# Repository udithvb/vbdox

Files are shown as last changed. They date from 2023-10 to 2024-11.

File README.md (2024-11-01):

DIY ergonomic keyboard clone "inspired" by Ergodox.

Source code for:
  1. PCB design in Kicad
  2. Keyboard layout using KLE.
  3. 3D model using Onshape
  4. Config files for KMK for firmware.

3D model files here https://cad.onshape.com/documents/ee7b6b641733c3f6c864279a/w/8fba0d1b41314f945c99cf82/e/c87f91dc97543009856402ba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

WhatsApp Image 2024-07-17 at 08 57 51

Clipped_image_20231214_193427

wiki:
	for flasing to rom hold bootsel before plugging -> mv to rpi folder
	for src code hold reset before plugging in + reset within 500ms -> mv to circuitpy folder

Use thonny, configure interpreter to circuipy generic device, uncomment debug to read serial console.

Rename boards for split to work:
	https://learn.adafruit.com/welcome-to-circuitpython/renaming-circuitpy

links for binaries:
	https://www.raspberrypi.com/documentation/microcontrollers/pico-series.html#resetting-flash-memory
	https://circuitpython.org/board/waveshare_rp2040_zero/
	https://github.com/KMKfw/kmk_firmware/blob/master/docs/en/Getting_Started.md

Edit config:
	Hold the reset key before plugging in, keep holding for 4 seconds after (topmost key on keeb) to get into the filesystem and edit config.

# Credits

-   Keyboard parts compiled by [joe-scotto ](https://github.com/joe-scotto/scottokeebs/tree/main/Extras/ScottoKicad).
-   Reversible hotswap sockets by [LouWii ](https://github.com/LouWii/ErgoMax/tree/master/libs).

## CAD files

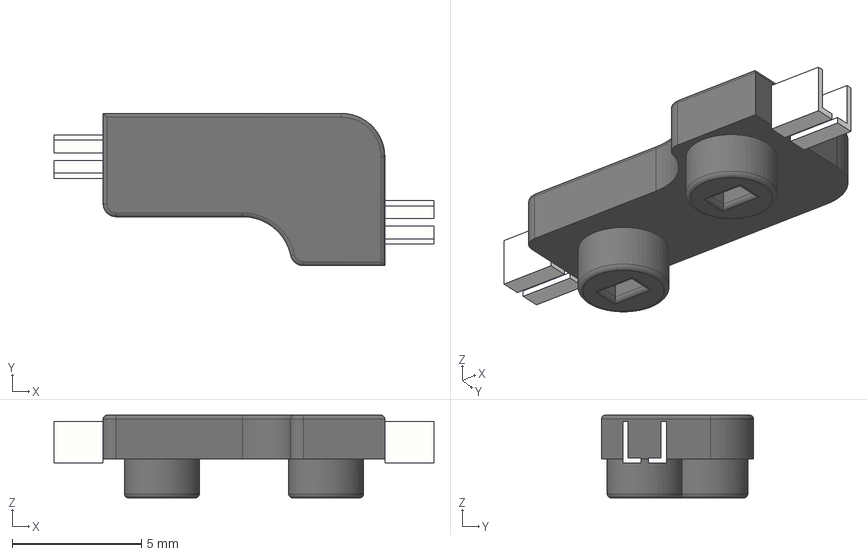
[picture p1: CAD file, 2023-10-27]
hardware/kicad_libs/3dmodels/Kailh_Socket.step
14.7 x 5.89 x 3.20 mm

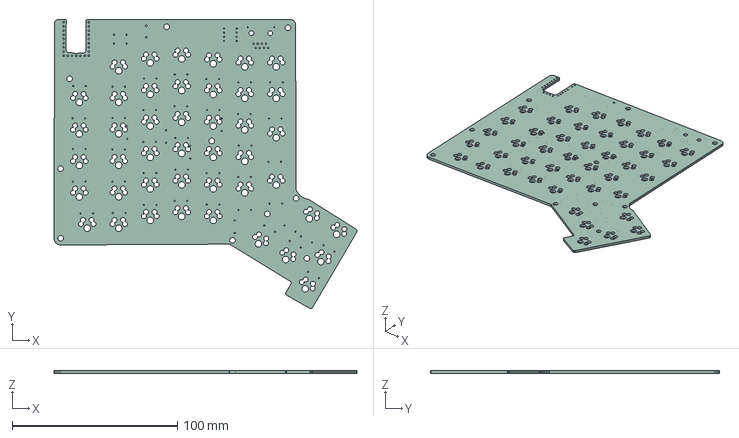
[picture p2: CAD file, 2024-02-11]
hardware/pcb/pcb.step
183.2 x 174.8 x 1.60 mm

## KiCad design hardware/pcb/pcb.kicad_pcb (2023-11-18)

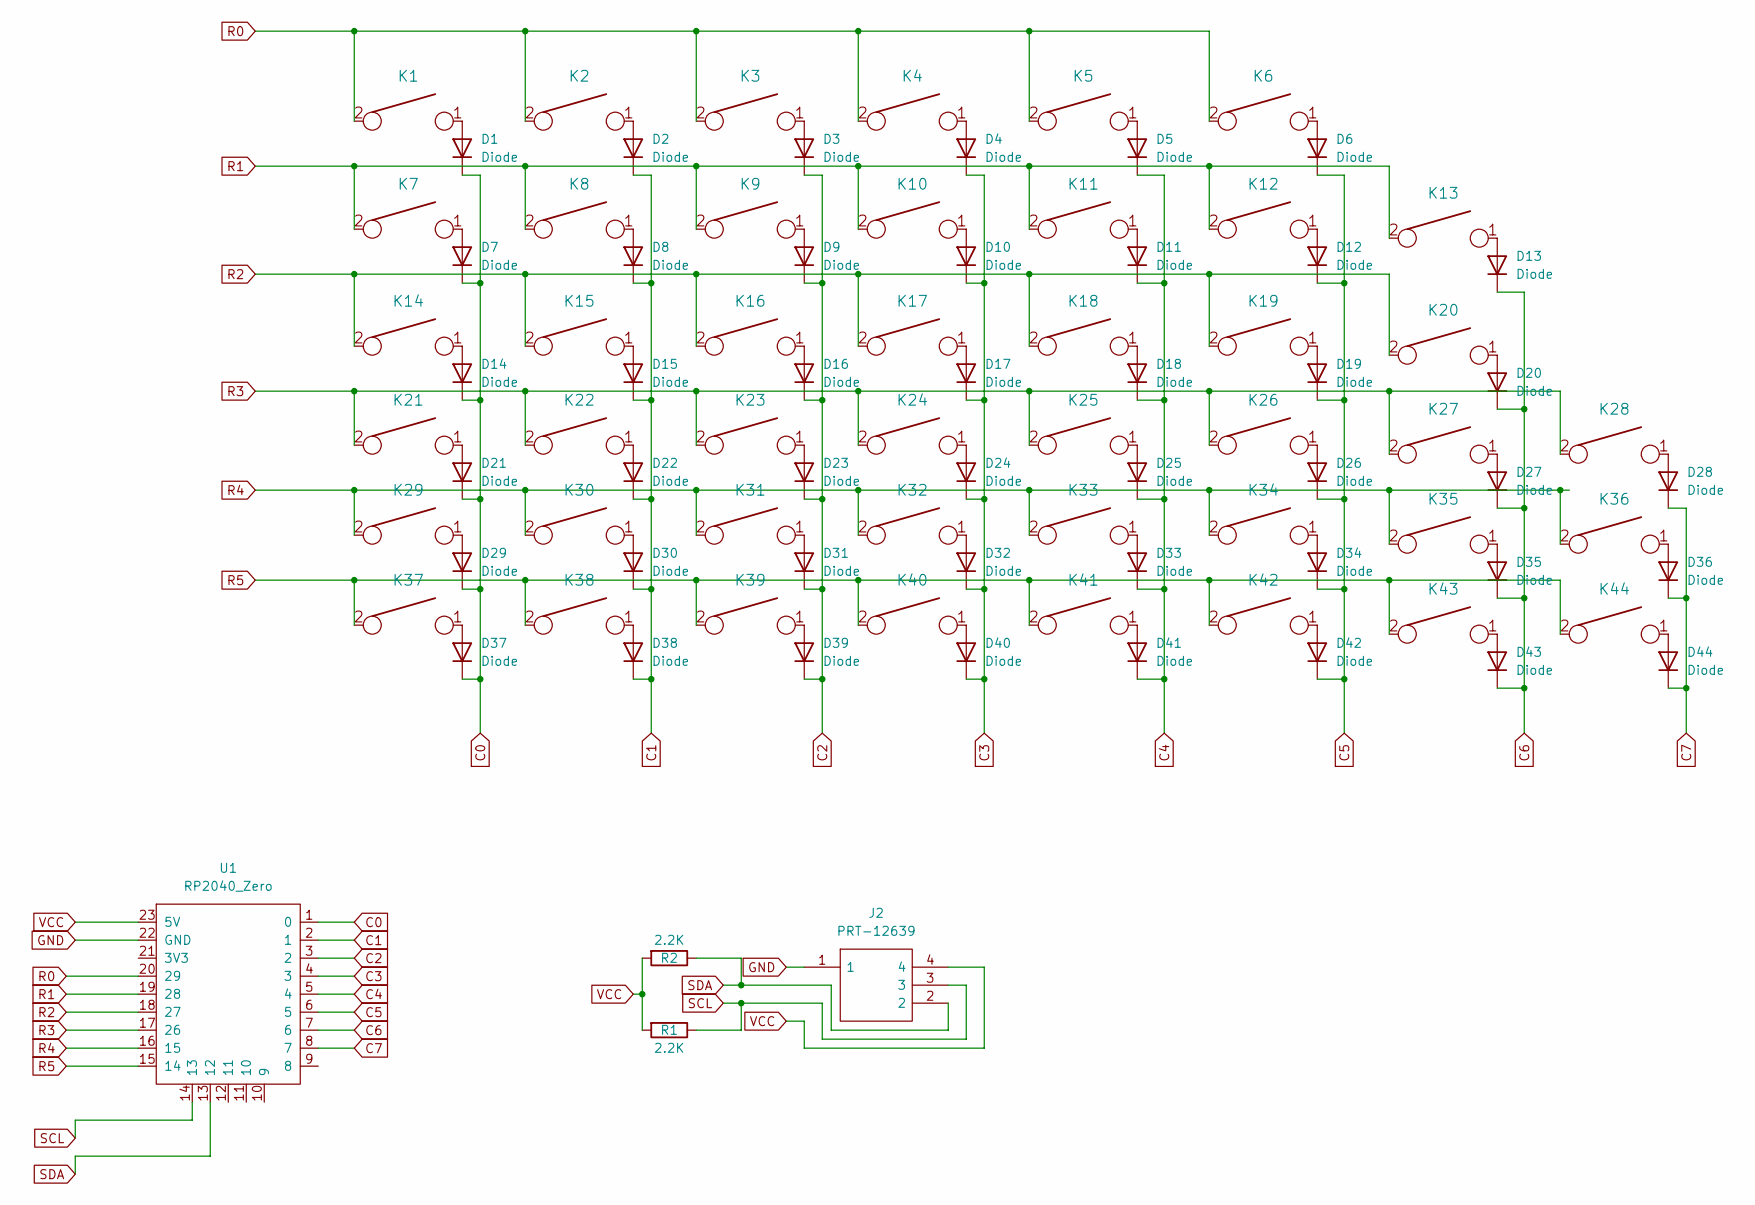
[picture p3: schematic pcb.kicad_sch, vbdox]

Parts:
D1, D2, D3, D4, D5, D6, D7, D8, D9, D10, D11, D12, D13, D14, D15, D16, D17, D18, D19, D20, D21, D22, D23, D24, D25, D26, D27, D28, D29, D30, D31, D32, D33, D34, D35, D36, D37, D38, D39, D40, D41, D42, D43, D44: Diode; Diode_DO-35
J2: PRT-12639; PRT12639; Mouser Part Number 474-PRT-12639
K1, K2, K3, K4, K5, K6, K7, K8, K9, K10, K11, K12, K13, K14, K15, K16, K17, K18, K19, K20, K21, K22, K23, K24, K25, K26, K27, K28, K29, K30, K31, K32, K33, K34, K35, K36, K37, K38, K39, K40, K41, K42, K43, K44: KEYSW; Kailh_MX_Socket_reversible
R1, R2: 2.2K; Diode_DO-35
U1: RP2040_Zero

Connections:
C0: D1.1 (K), D7.1 (K), D14.1 (K), D21.1 (K), D29.1 (K), D37.1 (K), U1.1 (0)
C1: D2.1 (K), D8.1 (K), D15.1 (K), D22.1 (K), D30.1 (K), D38.1 (K), U1.2 (1)
C2: D3.1 (K), D9.1 (K), D16.1 (K), D23.1 (K), D31.1 (K), D39.1 (K), U1.3 (2)
C3: D4.1 (K), D10.1 (K), D17.1 (K), D24.1 (K), D32.1 (K), D40.1 (K), U1.4 (3)
C4: D5.1 (K), D11.1 (K), D18.1 (K), D25.1 (K), D33.1 (K), D41.1 (K), U1.5 (4)
C5: D6.1 (K), D12.1 (K), D19.1 (K), D26.1 (K), D34.1 (K), D42.1 (K), U1.6 (5)
C6: D13.1 (K), D20.1 (K), D27.1 (K), D35.1 (K), D43.1 (K), U1.7 (6)
C7: D28.1 (K), D36.1 (K), D44.1 (K), U1.8 (7)
GND: U1.22 (GND); also elsewhere on the board
unnamed: D1.2 (A), K1.1
unnamed: D2.2 (A), K2.1
unnamed: D3.2 (A), K3.1
unnamed: D4.2 (A), K4.1
unnamed: D5.2 (A), K5.1
unnamed: D6.2 (A), K6.1
unnamed: D7.2 (A), K7.1
unnamed: D8.2 (A), K8.1
unnamed: D9.2 (A), K9.1
unnamed: D10.2 (A), K10.1
unnamed: D11.2 (A), K11.1
unnamed: D12.2 (A), K12.1
unnamed: D13.2 (A), K13.1
unnamed: D14.2 (A), K14.1
unnamed: D15.2 (A), K15.1
unnamed: D16.2 (A), K16.1
unnamed: D17.2 (A), K17.1
unnamed: D18.2 (A), K18.1
unnamed: D19.2 (A), K19.1
unnamed: D20.2 (A), K20.1
unnamed: D21.2 (A), K21.1
unnamed: D22.2 (A), K22.1
unnamed: D23.2 (A), K23.1
unnamed: D24.2 (A), K24.1
unnamed: D25.2 (A), K25.1
unnamed: D26.2 (A), K26.1
unnamed: D27.2 (A), K27.1
unnamed: D28.2 (A), K28.1
unnamed: D29.2 (A), K29.1
unnamed: D30.2 (A), K30.1
unnamed: D31.2 (A), K31.1
unnamed: D32.2 (A), K32.1
unnamed: D33.2 (A), K33.1
unnamed: D34.2 (A), K34.1
unnamed: D35.2 (A), K35.1
unnamed: D36.2 (A), K36.1
unnamed: D37.2 (A), K37.1
unnamed: D38.2 (A), K38.1
unnamed: D39.2 (A), K39.1
unnamed: D40.2 (A), K40.1
unnamed: D41.2 (A), K41.1
unnamed: D42.2 (A), K42.1
unnamed: D43.2 (A), K43.1
unnamed: D44.2 (A), K44.1
R0: K1.2, K2.2, K3.2, K4.2, K5.2, K6.2, U1.20 (29)
R1: K7.2, K8.2, K9.2, K10.2, K11.2, K12.2, K13.2, U1.19 (28)
R2: K14.2, K15.2, K16.2, K17.2, K18.2, K19.2, K20.2, U1.18 (27)
R3: K21.2, K22.2, K23.2, K24.2, K25.2, K26.2, K27.2, K28.2, U1.17 (26)
R4: K29.2, K30.2, K31.2, K32.2, K33.2, K34.2, K35.2, K36.2, U1.16 (15)
R5: K37.2, K38.2, K39.2, K40.2, K41.2, K42.2, K43.2, K44.2, U1.15 (14)
VCC: R1.2, R2.2, U1.23 (5V); also elsewhere on the board

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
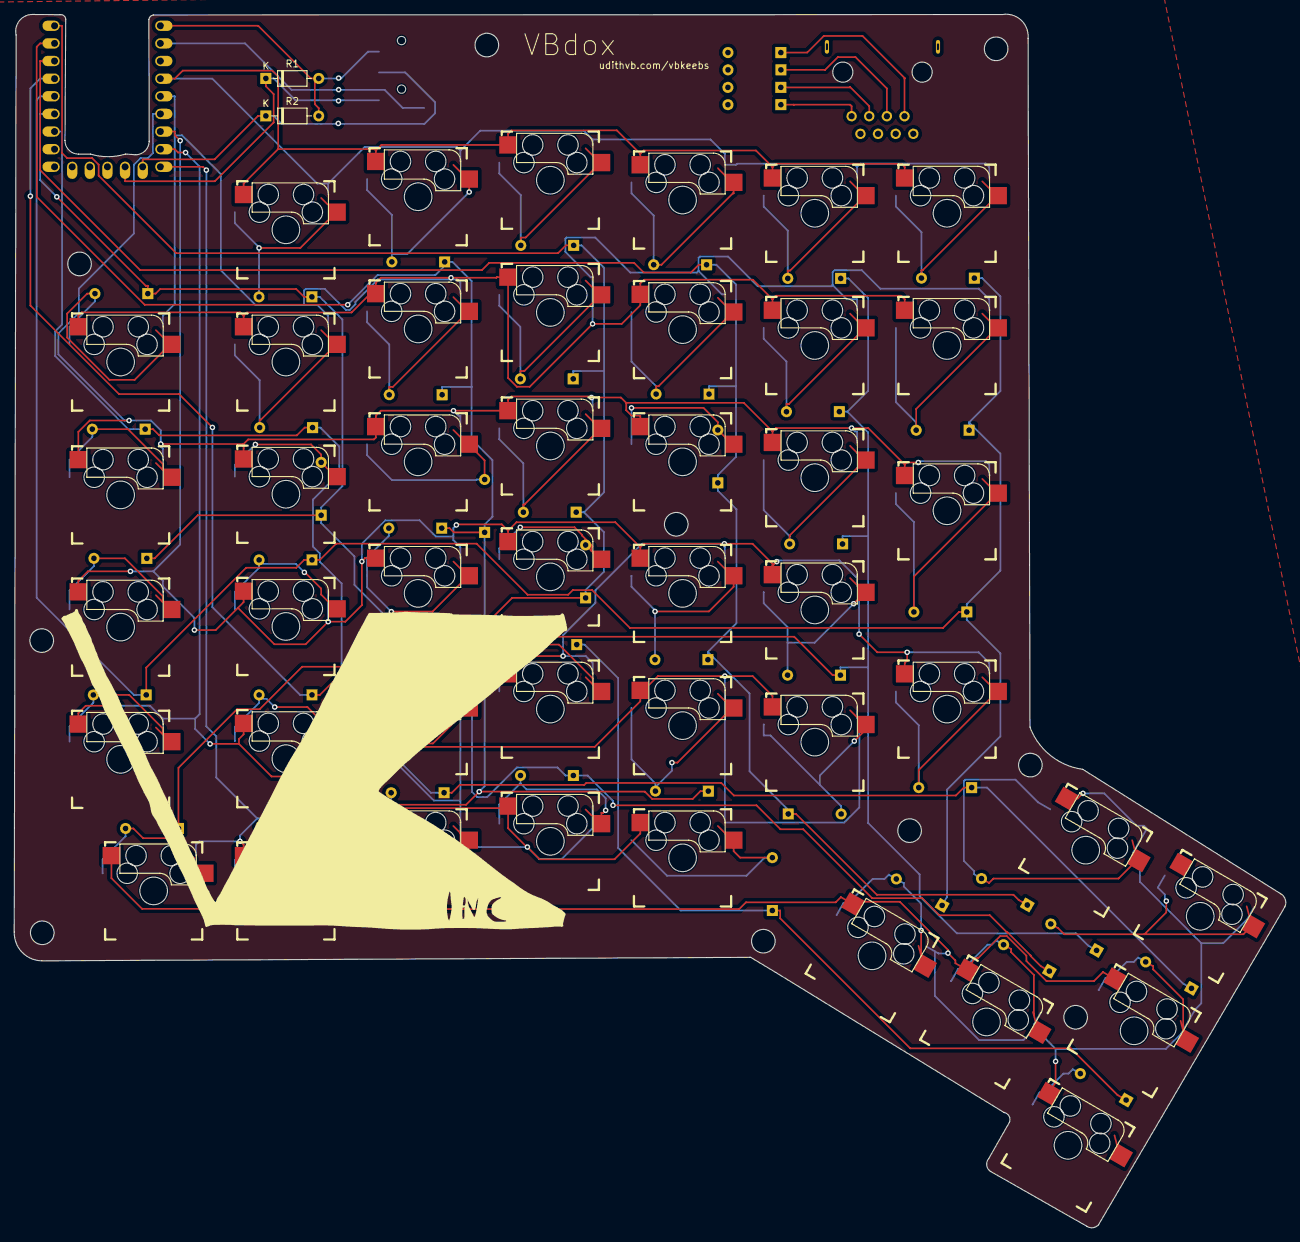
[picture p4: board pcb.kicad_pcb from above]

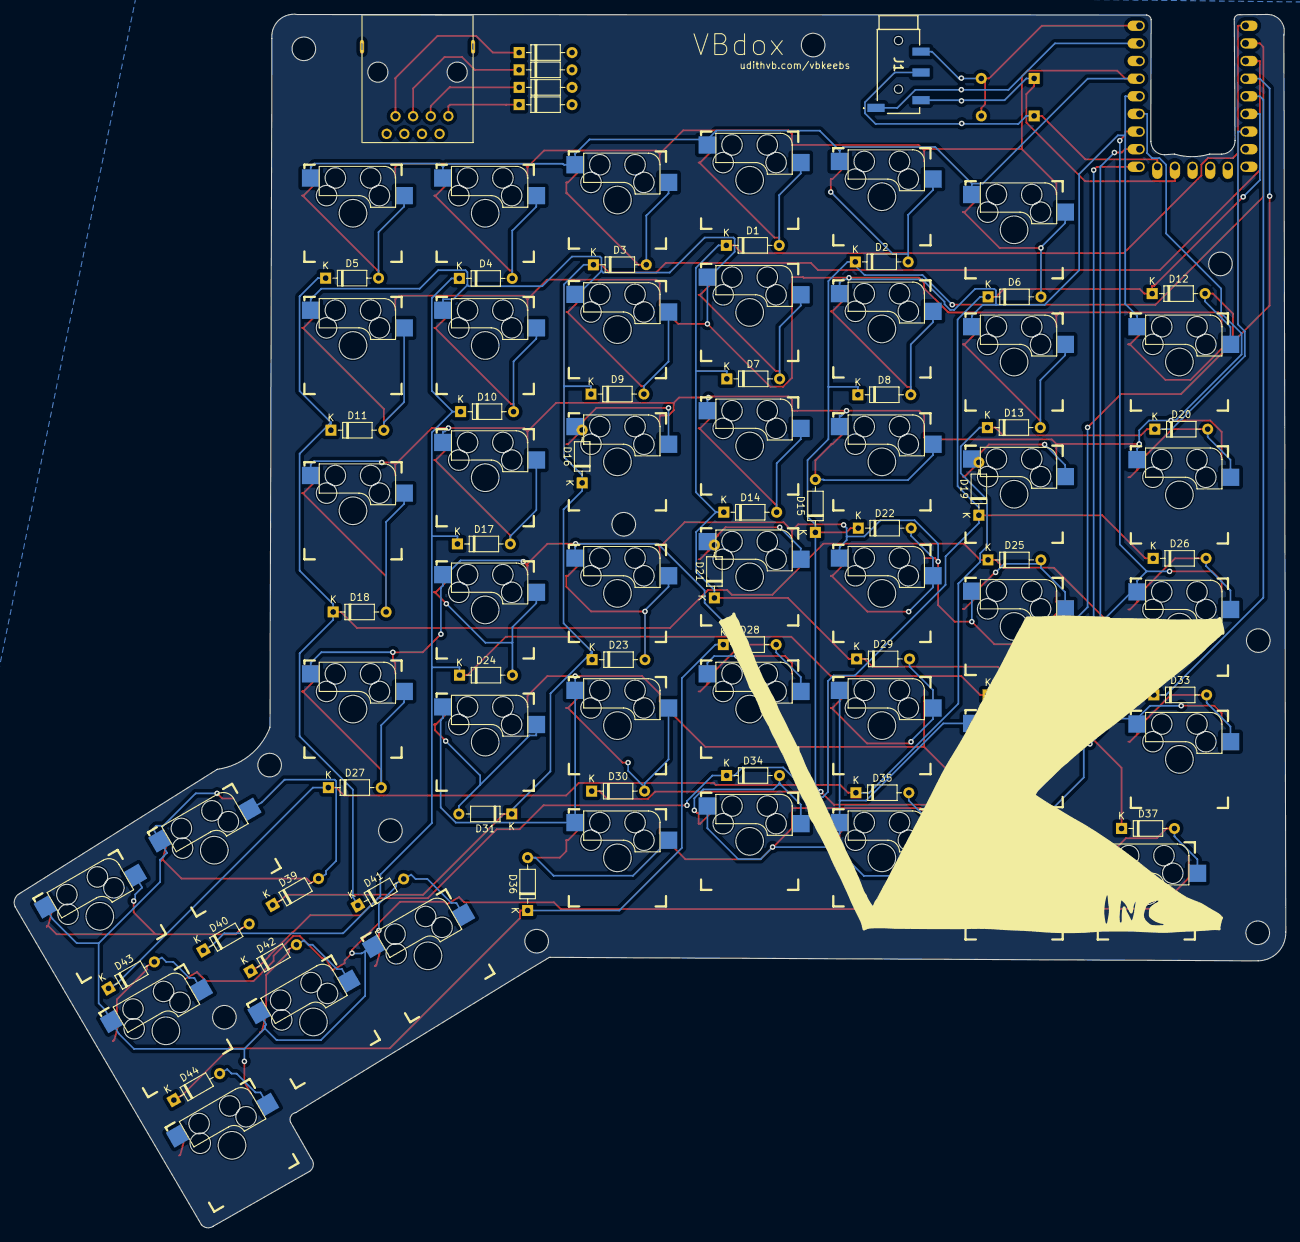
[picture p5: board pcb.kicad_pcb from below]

Board: 2 copper layers, 183.2 x 174.8 mm, 92 parts (46 on the bottom side), 62 nets.

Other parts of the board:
J1: PRT-12639; PRT12639

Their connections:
GND: J1.1; also elsewhere on the board
VCC: J1.4; also elsewhere on the board

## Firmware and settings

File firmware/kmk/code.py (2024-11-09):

print("started")

import board

from kmk.kmk_keyboard import KMKKeyboard
from kmk.keys import KC
from kmk.scanners import DiodeOrientation
from kmk.modules.split import Split, SplitType, SplitSide


keyboard = KMKKeyboard()

keyboard.col_pins = (board.GP0,board.GP1,board.GP2,board.GP3,board.GP4,board.GP5,board.GP6,board.GP7)
keyboard.row_pins = (board.GP29,board.GP28,board.GP27,board.GP26,board.GP15,board.GP14)

keyboard.diode_orientation = DiodeOrientation.ROW2COL
keyboard.debug_enabled = False
keyboard.tap_time = True



from kmk.modules.layers import Layers; keyboard.modules.append(Layers())
from kmk.modules.holdtap import HoldTap; keyboard.modules.append(HoldTap())
from kmk.modules.mouse_keys import MouseKeys; keyboard.modules.append(MouseKeys())
from kmk.modules.power import Power; keyboard.modules.append(Power())
from kmk.modules.tapdance import TapDance; keyboard.modules.append(TapDance())
from kmk.extensions.media_keys import MediaKeys; keyboard.extensions.append(MediaKeys())
from kmk.modules.capsword import CapsWord; keyboard.modules.append(CapsWord())




from kmk.handlers.sequences import simple_key_sequence, send_string   # depricated TODO: use macros
# https://github.com/KMKfw/kmk_firmware/blob/main/docs/en/macros.md
# from kmk.modules.macros import Macros;  keyboard.modules.append(Macros())



split = Split(data_pin=board.GP11, data_pin2=board.GP12, use_pio=True, uart_flip = True)
keyboard.modules.append(split)

XXXX = KC.NO
____ = KC.TRNS


tap_time = 150


TMUX_TAB  = simple_key_sequence((
         KC.LCTL(KC.A),
         KC.TAB,
))


TMUX_LW  = simple_key_sequence((
         KC.LCTL(KC.A),
         KC.SCOLON,
))


TMUX_ZM  = simple_key_sequence((
         KC.LCTL(KC.A),
         KC.Z,
))

TMUX = KC.TD(
    TMUX_TAB,
    KC.HT(TMUX_LW,TMUX_ZM,prefer_hold=False),
    XXXX
)


I3 = KC.TD(
    KC.LALT(KC.TAB),
    KC.HT(KC.LALT(KC.TAB),KC.LALT(KC.LSFT(KC.TAB)),prefer_hold=False),
    XXXX,
    XXXX
)

PASS_STR = send_string("pass")


PASS = KC.TD(
    KC.F3,
    XXXX,
    KC.HT(XXXX,PASS_STR,prefer_hold=False),
    XXXX
)


keyboard.coord_mapping = [
         5,  1,  0,  2,  3,  4,       52, 51, 50, 48, 49, 53,
    13, 14,  9,  8, 10, 11, 12,       60, 59, 58, 56, 57, 62, 61,
    22, 21, 17, 16, 18, 19, 20,       68, 67, 66, 64, 65, 69, 70,
    29, 28, 25, 24, 26, 27, 30,       78, 75, 74, 72, 73, 76, 77,
    36, 35, 32, 31, 33, 34,               82, 81, 79, 80, 83, 84,
    40, 41, 38, 37, 39,                       87, 85, 86, 89, 88,
                        42, 43,       91, 90,
                    44, 45, 46,       94, 93, 92,
                            47,       95,
    ]



#KC.TD(KC.NO, KC.DF(), tap_time=200)

keyboard.keymap = [
    
    #BASE
    [
                  XXXX,  KC.F2,  PASS,  KC.F4,  KC.F5, KC.F6,             KC.F7, KC.F8, KC.F9, KC.F10, KC.F11, KC.F12,
        I3,   KC.LALT(KC.N1),   KC.LALT(KC.N2),   KC.LALT(KC.N3),   KC.LALT(KC.N4),   KC.LALT(KC.N5),  KC.LALT(KC.N6),      KC.LALT(KC.N7), KC.LALT(KC.N8), KC.LALT(KC.N9), KC.LALT(KC.N0), KC.MINUS, KC.EQUAL, TMUX,
        XXXX,KC.Q, KC.W, KC.F, KC.P, KC.B,XXXX,                             XXXX, KC.J, KC.L, KC.U, KC.Y, KC.SCLN, XXXX,
        XXXX,KC.HT(KC.A, KC.LGUI, prefer_hold=False, tap_interrupted=True, tap_time=tap_time), KC.HT(KC.R, KC.LGUI, prefer_hold=False, tap_interrupted=True, tap_time=tap_time), KC.HT(KC.S, KC.LALT, prefer_hold=False, tap_interrupted=True, tap_time=tap_time), KC.HT(KC.T, KC.LCTL, prefer_hold=False, tap_interrupted=True, tap_time = tap_time), KC.G, XXXX,                             XXXX,KC.M, KC.HT(KC.N, KC.LCTL, prefer_hold=False, tap_interrupted=True, tap_time=tap_time), KC.HT(KC.E, KC.LALT, prefer_hold=False, tap_interrupted=True, tap_time=tap_time), KC.HT(KC.I, KC.LGUI, prefer_hold=False, tap_interrupted=True, tap_time=tap_time), KC.HT(KC.O, KC.LGUI, prefer_hold=False, tap_interrupted=True, tap_time=tap_time),XXXX,
        XXXX,KC.LT(3, KC.Z, prefer_hold=True, tap_interrupted=False, tap_time=tap_time), KC.HT(KC.X, KC.RALT, prefer_hold=False, tap_interrupted=True, tap_time=tap_time), KC.C, KC.HT(KC.D, KC.LSFT, prefer_hold=False, tap_interrupted=True, tap_time=tap_time), KC.V,             KC.K, KC.HT(KC.H, KC.LSFT, prefer_hold=False, tap_interrupted=True, tap_time=tap_time), KC.COMM, KC.HT(KC.DOT, KC.RALT, prefer_hold=False, tap_interrupted=True, tap_time=tap_time), KC.LT(3, KC.SLSH, prefer_hold=True, tap_interrupted=False, tap_time=tap_time), XXXX,
        XXXX,XXXX,XXXX,XXXX,KC.LT(6, KC.ESC, prefer_hold=True, tap_interrupted=False, tap_time=tap_time),      KC.LT(9, KC.DEL, prefer_hold=True, tap_interrupted=False, tap_time=tap_time),XXXX,XXXX,XXXX,XXXX,
        XXXX,XXXX,      XXXX,XXXX,
        KC.LT(3, KC.SPC, prefer_hold=True, tap_interrupted=False, tap_time=tap_time), KC.LT(5, KC.TAB, prefer_hold=True, tap_interrupted=False, tap_time=tap_time),XXXX,                     XXXX,KC.LT(4, KC.ENT, prefer_hold=True, tap_interrupted=False, tap_time=tap_time), KC.LT(2, KC.BSPC, prefer_hold=True, tap_interrupted=False, tap_time=tap_time),
        XXXX,                           XXXX,
        ],
    #LAYER_TEMPLATE
    
       [
             XXXX,XXXX,XXXX,XXXX,XXXX,XXXX,        XXXX,XXXX,XXXX,XXXX,XXXX,XXXX,
        ____,KC.LALT(KC.N1),KC.LALT(KC.N2),XXXX,XXXX,XXXX,XXXX,        XXXX,XXXX,XXXX,XXXX,XXXX,XXXX,XXXX,
        XXXX,XXXX,XXXX,XXXX,XXXX,XXXX,XXXX,        XXXX,XXXX,XXXX,XXXX,XXXX,XXXX,XXXX,
        XXXX,XXXX,XXXX,XXXX,XXXX,XXXX,XXXX,        XXXX,XXXX,XXXX,XXXX,XXXX,XXXX,XXXX,
        XXXX,XXXX,XXXX,XXXX,XXXX,XXXX,                  XXXX,XXXX,XXXX,XXXX,XXXX,XXXX,
        XXXX,XXXX,XXXX,XXXX,XXXX,                            XXXX,XXXX,XXXX,XXXX,XXXX,
                                 XXXX,XXXX,        XXXX,XXXX,
                            XXXX,XXXX,XXXX,        XXXX,XXXX,XXXX,
                                      XXXX,        XXXX
        
        ],
#       [
#             XXXX,XXXX,XXXX,XXXX,XXXX,XXXX,        XXXX,XXXX,XXXX,XXXX,XXXX,XXXX,
#        XXXX,XXXX,XXXX,XXXX,XXXX,XXXX,XXXX,        XXXX,XXXX,XXXX,XXXX,XXXX,XXXX,XXXX,
#        XXXX,XXXX,XXXX,XXXX,XXXX,XXXX,XXXX,        XXXX,XXXX,XXXX,XXXX,XXXX,XXXX,XXXX,
#        XXXX,XXXX,XXXX,XXXX,XXXX,XXXX,XXXX,        XXXX,XXXX,XXXX,XXXX,XXXX,XXXX,XXXX,
#        XXXX,XXXX,XXXX,XXXX,XXXX,XXXX,                  XXXX,XXXX,XXXX,XXXX,XXXX,XXXX,
#        XXXX,XXXX,XXXX,XXXX,XXXX,                            XXXX,XXXX,XXXX,XXXX,XXXX,
#                                 XXXX,XXXX,        XXXX,XXXX,
#                            XXXX,XXXX,XXXX,        XXXX,XXXX,XXXX,
#                                      XXXX,        XXXX
#        
#        ],
    #NUMBER
    [
        XXXX,XXXX,XXXX,XXXX,XXXX,XXXX,     XXXX,XXXX,XXXX,XXXX,XXXX,XXXX,
        XXXX,XXXX,XXXX,XXXX,XXXX,XXXX,XXXX,     XXXX,XXXX,XXXX,XXXX,XXXX,XXXX,XXXX,
        XXXX,KC.LBRC,KC.N7,KC.N8,KC.N9,KC.RBRC,XXXX,        XXXX,XXXX,XXXX,XXXX,XXXX,XXXX,XXXX,
        XXXX,KC.QUOT,KC.N4,KC.N5,KC.N6,KC.EQL,XXXX,        XXXX,XXXX,XXXX,XXXX,XXXX,XXXX,XXXX,
        XXXX,KC.GRV,KC.N1,KC.N2,KC.N3,KC.BSLS,             XXXX,XXXX,XXXX,XXXX,XXXX,XXXX,
        XXXX,XXXX,XXXX,XXXX,XXXX,                  XXXX,XXXX,XXXX,XXXX,XXXX,
                       XXXX,XXXX,                  XXXX,XXXX,
                  KC.N0,KC.MINUS,XXXX,                 XXXX,XXXX,XXXX,
                            XXXX,                  XXXX
        
        ],
       
       #NAV
    
       [
             XXXX,XXXX,XXXX,XXXX,XXXX,XXXX,        XXXX,XXXX,XXXX,XXXX,XXXX,XXXX,
        XXXX,XXXX,XXXX,XXXX,XXXX,XXXX,XXXX,        XXXX,XXXX,XXXX,XXXX,XXXX,XXXX,XXXX,
        XXXX,XXXX,XXXX,XXXX,XXXX,XXXX,XXXX,        XXXX,XXXX,XXXX,XXXX,XXXX,XXXX,XXXX,
        XXXX,XXXX,XXXX,XXXX,XXXX,XXXX,XXXX,        XXXX,KC.LEFT,KC.DOWN,KC.UP,KC.RIGHT,XXXX,XXXX,
        XXXX,XXXX,XXXX,XXXX,XXXX,XXXX,                  KC.HOME,KC.PGDOWN,KC.PGUP,KC.END,XXXX,XXXX,
        XXXX,XXXX,XXXX,XXXX,XXXX,                            XXXX,XXXX,XXXX,XXXX,XXXX,
                                 XXXX,XXXX,        XXXX,XXXX,
                            XXXX,XXXX,XXXX,        XXXX,XXXX,XXXX,
                                      XXXX,        XXXX
        
        ],
        #SYMBOL
    
       [
             XXXX,XXXX,XXXX,XXXX,XXXX,XXXX,        XXXX,XXXX,XXXX,XXXX,XXXX,XXXX,
        XXXX,XXXX,XXXX,XXXX,XXXX,XXXX,XXXX,        XXXX,XXXX,XXXX,XXXX,XXXX,XXXX,XXXX,
        XXXX,KC.LCBR,KC.AMPR,KC.ASTR,KC.RPRN,KC.RCBR,XXXX,        XXXX,XXXX,XXXX,XXXX,XXXX,XXXX,XXXX,
        XXXX,KC.DQT,KC.DLR,KC.PERC,KC.CIRC,KC.PLUS,XXXX,        XXXX,XXXX,XXXX,XXXX,XXXX,XXXX,XXXX,
        XXXX,KC.TILD,KC.EXLM,KC.AT,KC.HASH,KC.PIPE,                  XXXX,XXXX,XXXX,XXXX,XXXX,XXXX,
        XXXX,XXXX,XXXX,XXXX,KC.LPRN,                            XXXX,XXXX,XXXX,XXXX,XXXX,
                                 XXXX,XXXX,        XXXX,XXXX,
                            KC.RPRN,KC.UNDS,XXXX,        XXXX,XXXX,XXXX,
                                      XXXX,        XXXX
        
        ],
     #MOUSE
    
       [
             XXXX,XXXX,XXXX,XXXX,XXXX,XXXX,        XXXX,XXXX,XXXX,XXXX,XXXX,XXXX,
        XXXX,XXXX,XXXX,XXXX,XXXX,XXXX,XXXX,        XXXX,XXXX,XXXX,XXXX,XXXX,XXXX,XXXX,
        XXXX,XXXX,XXXX,XXXX,XXXX,XXXX,XXXX,        XXXX,XXXX,XXXX,XXXX,XXXX,XXXX,XXXX,
        XXXX,XXXX,XXXX,XXXX,XXXX,XXXX,XXXX,        XXXX,KC.MS_LT,KC.MS_DN,KC.MS_UP,KC.MS_RT,XXXX,XXXX,
        XXXX,XXXX,XXXX,XXXX,XXXX,XXXX,                  KC.MW_LT,KC.MW_DN,KC.MW_UP,KC.MW_RT,XXXX,XXXX,
        XXXX,XXXX,XXXX,XXXX,XXXX,                            XXXX,XXXX,XXXX,XXXX,XXXX,
                                 XXXX,XXXX,        XXXX,XXXX,
                            XXXX,XXXX,XXXX,        KC.MB_RMB,KC.MB_LMB,KC.MB_MMB,
                                      XXXX,        XXXX
        
        ],

  
    
    ]

layer_names_list = [
"Base", "LayerTemplate", "Number","Nav","Symbol","Mouse",
]

if __name__ == '__main__':
    keyboard.go()
# # 

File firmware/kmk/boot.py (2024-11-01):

import board

from kmk.bootcfg import bootcfg

# bootcfg(
#     # required:
#     sense: [microcontroller.Pin, digitalio.DigitalInOut],
#     # optional:
#     source: Optional[microcontroller.Pin, digitalio.DigitalInOut] = None,
#     boot_device: int = 0,
#     cdc: bool = True,
#     consumer_control: bool = True,
#     keyboard: bool = True,
#     midi: bool = False,
#     mouse: bool = True,
#     nkro: bool = False,
#     pan: bool = True,
#     storage: bool = True,
#     usb_id: Optional[tuple[str, str]] = None,
#     **kwargs,
# ) -> bool




from kmk.bootcfg import bootcfg

bootcfg(
    sense=board.GP29,
    source=board.GP0,
    midi=False,
    mouse=True,
    pan=False,
    storage=False,
    usb_id=('VBinc.', 'vbdox'),
)

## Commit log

2023-10-27 init kicad project
    [pcb.kicad_pcb, pcb.kicad_sch]
2023-10-27 added kicad libs
    [Kailh_Socket.step, pcb.kicad_pcb, pcb.kicad_sch]
2023-10-29 added 6X8 matrix and global labels
    [pcb.kicad_pcb, pcb.kicad_sch]
2023-10-29 schema init
    [pcb.kicad_pcb, pcb.kicad_sch]
2023-10-31 placed switched to ergomax layout using plugin, and added edge cuts for castelled rp2040 zero
    [pcb.kicad_pcb]
2023-11-18 removed outline, to add rj45
    [pcb.kicad_pcb]
2024-02-11 PCB step file
    [pcb.step]
2024-02-17 fix { instead of }
    [code.py]
